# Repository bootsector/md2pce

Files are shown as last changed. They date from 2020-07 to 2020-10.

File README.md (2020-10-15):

# MD2PCE - Sega Genesis controller adapter for TG16/PC-Engine and USB!
(c) Bruno Freitas - 10/2020 - http://www.brunofreitas.com/

This project is Open Source (GPLv3) and Open Hardware (CC BY-SA 4.0)

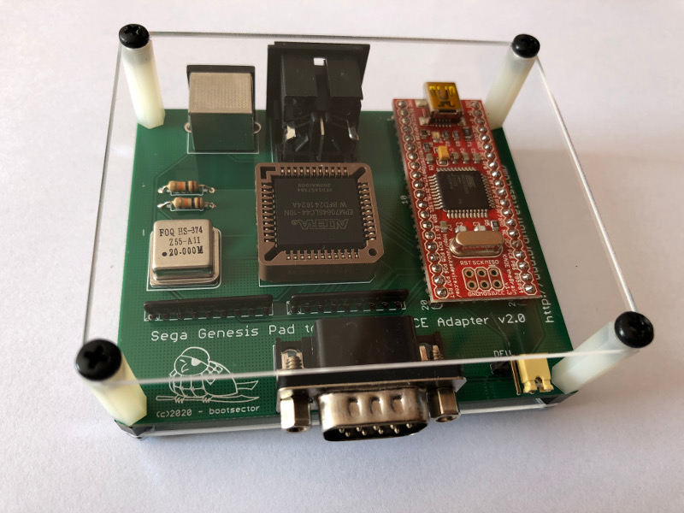
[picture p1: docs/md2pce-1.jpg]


MD2PCE is an adapter that allows you to connect Sega Genesis controllers to the TurboGrafx16, PC-Engine and also PC via USB (XInput).

It's compatible with both 3 and 6 buttons Sega Genesis controllers. It also supports the 8BitDo M30 2.4g with its wireless DB9 receiver.

MD2PCE Adapter starts in 2 button mode, which ensures 100% compatibility with all PCE/TG16 games catalog. For games supporting 6 button controllers, you can switch to 6 button mode, and also switching back to 2 button mode, by pressing the combo keys: UP + B + C + Start.

Mappings for both 2 and 6 button modes are:

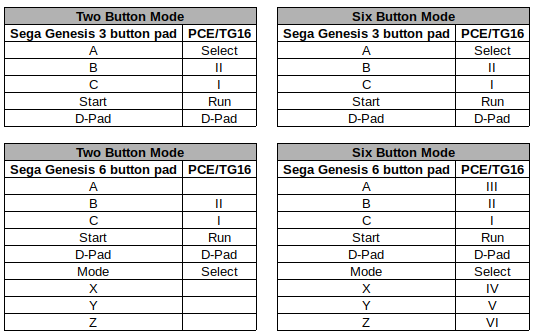
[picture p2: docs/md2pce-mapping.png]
MD2PCE Button Mapping


The adapter needs male-male 8 pin DIN (TG16) or Mini-DIN (PCE) cables that must be purchased separately.

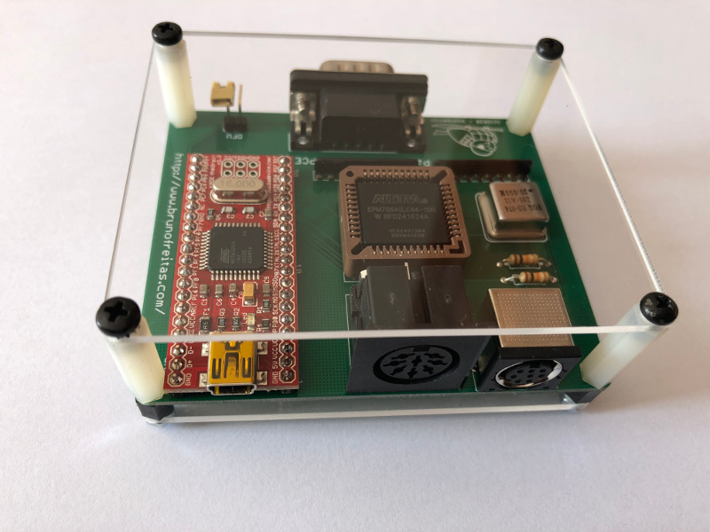
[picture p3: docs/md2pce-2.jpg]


For using on PC via USB, you'll need a mini-USB cable that also must be purchased separately.

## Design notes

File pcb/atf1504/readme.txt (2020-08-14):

This shield is based on https://github.com/hackup/ATF2FT232HQ

If CPLD is used and it needs JTAG erasing, connect a 12V PSU and run (OpenOCD version 0.10.0-rc2):

bin-x64\openocd.exe -f scripts\interface\ftdi\um232h.cfg -c "adapter_khz 400" -c "transport select jtag" -c "jtag newtap ATF1504AS tap -irlen 3 -expected-id 0x0150403f" -c init -c "svf atf1504as-erase.svf" -c "sleep 200" -c shutdown

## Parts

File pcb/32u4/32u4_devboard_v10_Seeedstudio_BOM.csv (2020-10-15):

Parts | OPL SKU | Qty
C1,C6,C7,C9 | 302010165 | 4
R1,R5 | 301010361 | 2
C8 | 302020011 | 1
XTAL | 306010037 | 1
C2,C3 | 302010143 | 2
R4 | 301010311 | 1
C4 | 302010179 | 1
R2,R3 | 301010329 | 2
32U4-AU | 310010010 | 1
F1 | 307010002 | 1
Led | 304090046 | 1
USB | 320010014 | 1

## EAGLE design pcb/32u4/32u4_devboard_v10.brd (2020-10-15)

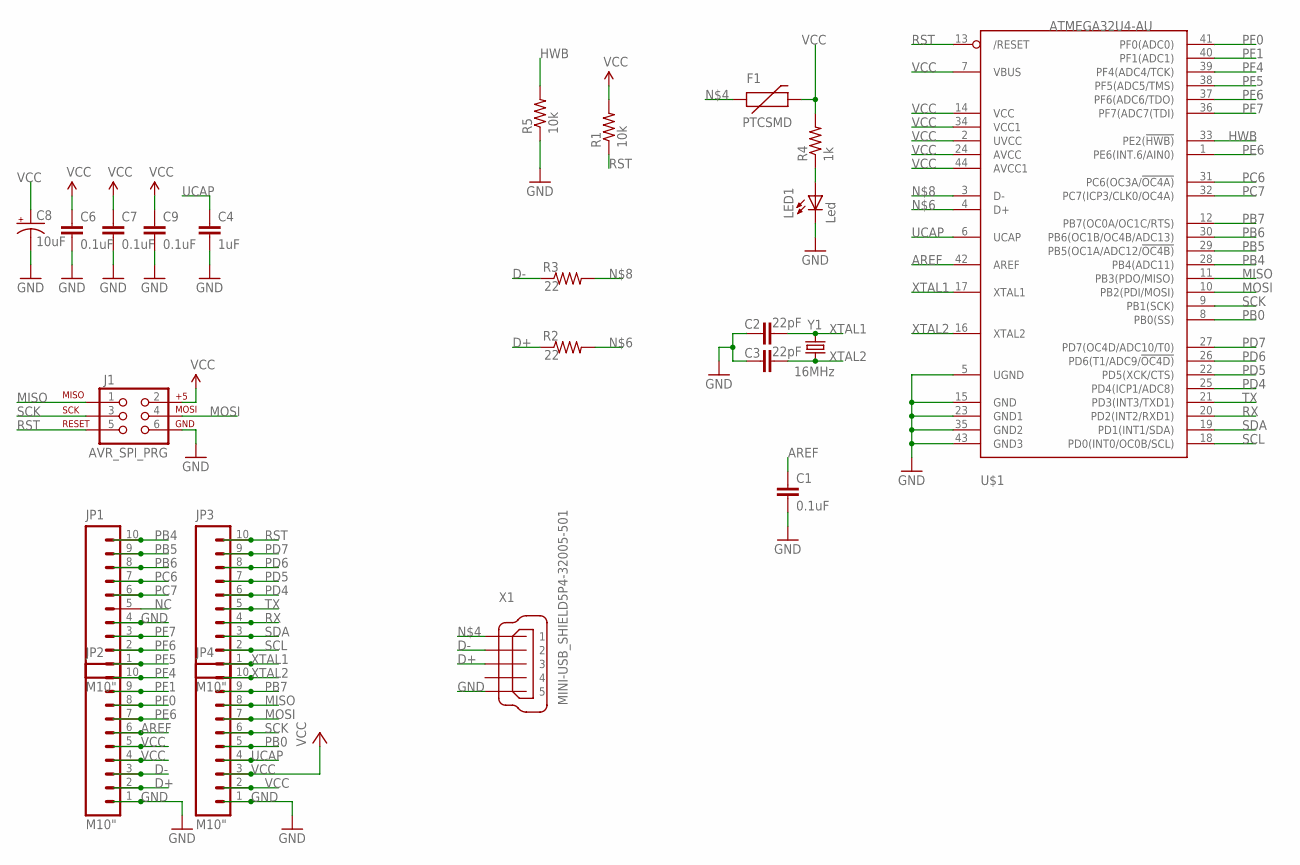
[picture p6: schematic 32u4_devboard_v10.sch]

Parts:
C1, C6, C7, C9: 0.1uF; 0805
C2, C3: 22pF; 0603-CAP
C4: 1uF; 0805
C8: 10uF; EIA3216
F1: PTCSMD; PTC-1206
J1: AVR_SPI_PRG; 2X3
JP1, JP2, JP3, JP4: M10"; 1X10
LED1: Led; CHIP-LED0805
R1, R5: 10k; 0805
R2, R3: 22; 0805
R4: 1k; 0805
U$1: ATMEGA32U4-AU; TQFP44
X1: MINI-USB_SHIELD5P4-32005-501; 32005-501
Y1: 16MHz; HC49US

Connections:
AREF: C1.1, JP2.6, U$1.42 (AREF)
D+: JP2.2, R2.1, X1.3
D-: JP2.3, R3.1, X1.2
GND: C1.2, C2.1, C3.1, C4.2, C6.2, C7.2, C8.C (-), C9.2, J1.6, JP1.4, JP2.1, JP4.1, LED1.C, R5.1, U$1.5 (UGND), U$1.15 (GND), U$1.23 (GND1), U$1.35 (GND2), U$1.43 (GND3), X1.5
HWB: R5.2, U$1.33 (PE2(!HWB))
MISO: J1.1, JP4.8, U$1.11 (PB3(PDO/MISO))
MOSI: J1.4, JP4.7, U$1.10 (PB2(PDI/MOSI))
unnamed: F1.1, X1.1
unnamed: R2.2, U$1.4 (D+)
unnamed: R3.2, U$1.3 (D-)
unnamed: LED1.A, R4.1
NC: JP1.5
PB0: JP4.5, U$1.8 (PB0(SS))
PB4: JP1.10, U$1.28 (PB4(ADC11))
PB5: JP1.9, U$1.29 (PB5(OC1A/ADC12/!OC4B))
PB6: JP1.8, U$1.30 (PB6(OC1B/OC4B/ADC13))
PB7: JP4.9, U$1.12 (PB7(OC0A/OC1C/RTS))
PC6: JP1.7, U$1.31 (PC6(OC3A/!OC4A))
PC7: JP1.6, U$1.32 (PC7(ICP3/CLK0/OC4A))
PD4: JP3.6, U$1.25 (PD4(ICP1/ADC8))
PD5: JP3.7, U$1.22 (PD5(XCK/CTS))
PD6: JP3.8, U$1.26 (PD6(T1/ADC9/!OC4D))
PD7: JP3.9, U$1.27 (PD7(OC4D/ADC10/T0))
PE6: JP2.7, U$1.1 (PE6(INT.6/AIN0))
PF0: JP2.8, U$1.41 (PF0(ADC0))
PF1: JP2.9, U$1.40 (PF1(ADC1))
PF4: JP2.10, U$1.39 (PF4(ADC4/TCK))
PF5: JP1.1, U$1.38 (PF5(ADC5/TMS))
PF6: JP1.2, U$1.37 (PF6(ADC6/TDO))
PF7: JP1.3, U$1.36 (PF7(ADC7(TDI))
RST: J1.5, JP3.10, R1.1, U$1.13 (/RESET)
RX: JP3.4, U$1.20 (PD2(INT2/RXD1))
SCK: J1.3, JP4.6, U$1.9 (PB1(SCK))
SCL: JP3.2, U$1.18 (PD0(INT0/OC0B/SCL))
SDA: JP3.3, U$1.19 (PD1(INT1/SDA))
TX: JP3.5, U$1.21 (PD3(INT3/TXD1))
UCAP: C4.1, JP4.4, U$1.6 (UCAP)
VCC: C6.1, C7.1, C8.A (+), C9.1, F1.2, J1.2, JP2.4, JP2.5, JP4.2, JP4.3, R1.2, R4.2, U$1.2 (UVCC), U$1.7 (VBUS), U$1.14 (VCC), U$1.24 (AVCC), U$1.34 (VCC1), U$1.44 (AVCC1)
XTAL1: C2.2, JP3.1, U$1.17 (XTAL1), Y1.2
XTAL2: C3.2, JP4.10, U$1.16 (XTAL2), Y1.1

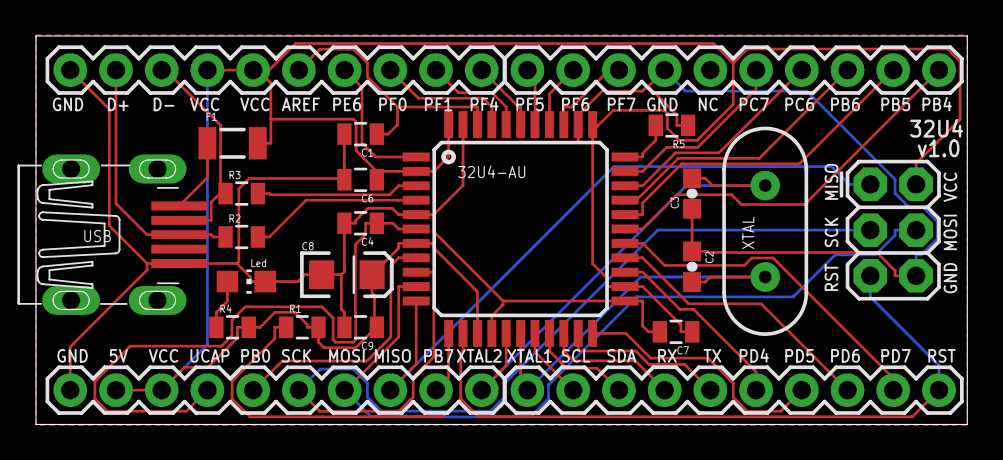
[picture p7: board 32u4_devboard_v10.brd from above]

Board: 2 copper layers, 51.7 x 21.6 mm, 23 parts (0 on the bottom side), 39 nets.

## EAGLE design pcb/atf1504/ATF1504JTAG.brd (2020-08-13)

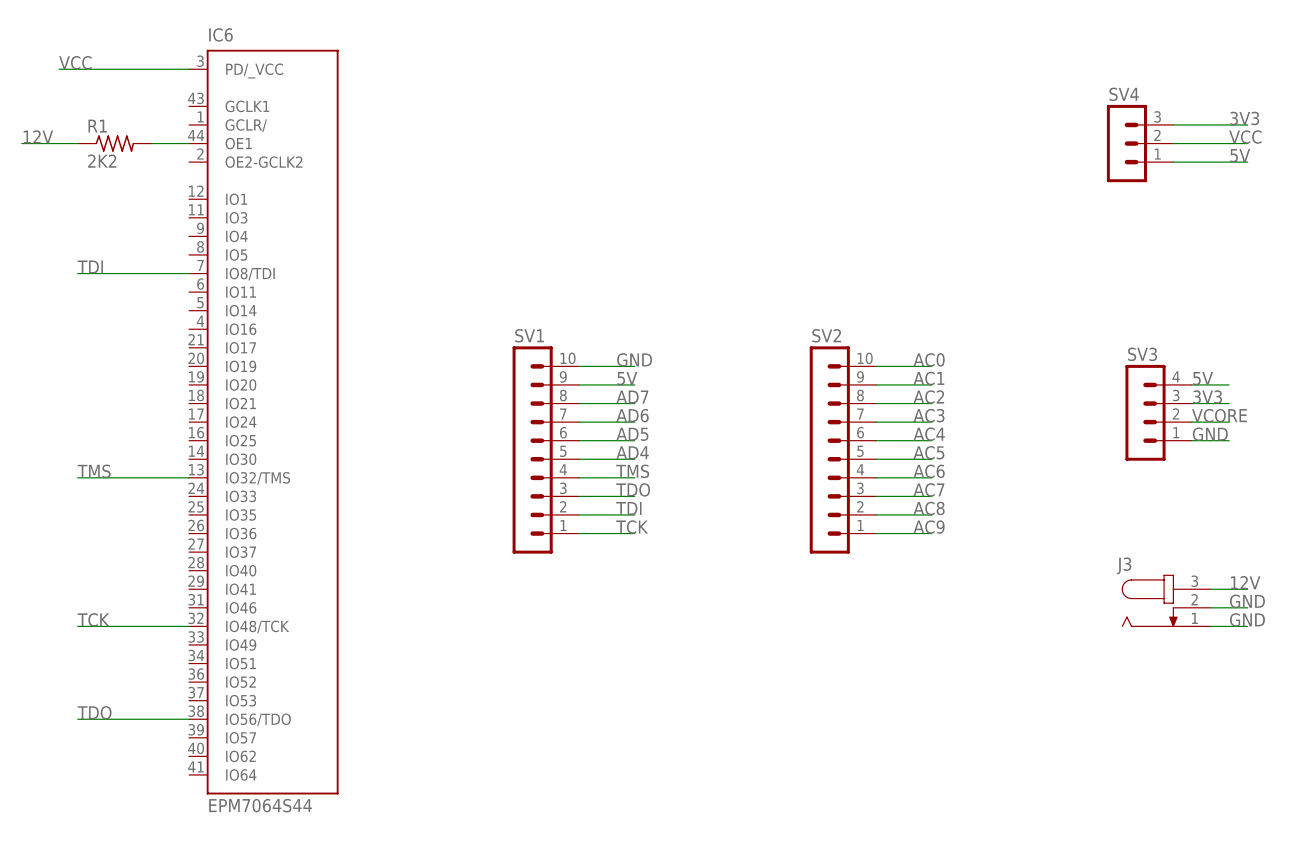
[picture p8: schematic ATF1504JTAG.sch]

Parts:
IC6: EPM7064S44; PLCC-S44
J3: JACK-PLUG1; SPC4078
R1: 2K2; 0207/10
SV1, SV2: MA10-1
SV3: MA04-1
SV4: MA03-1

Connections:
3V3: SV3.3, SV4.3
5V: SV1.9, SV3.4, SV4.1
12V: J3.3, R1.1
AC0: SV2.10
AC1: SV2.9
AC2: SV2.8
AC3: SV2.7
AC4: SV2.6
AC5: SV2.5
AC6: SV2.4
AC7: SV2.3
AC8: SV2.2
AC9: SV2.1
AD4: SV1.5
AD5: SV1.6
AD6: SV1.7
AD7: SV1.8
GND: IC6.10 (GND), IC6.22 (GND), IC6.30 (GND), IC6.42 (GND), J3.1, J3.2, SV1.10, SV3.1
unnamed: IC6.44 (OE1), R1.2
TCK: IC6.32 (IO48/TCK), SV1.1
TDI: IC6.7 (IO8/TDI), SV1.2
TDO: IC6.38 (IO56/TDO), SV1.3
TMS: IC6.13 (IO32/TMS), SV1.4
VCC: IC6.3 (PD/_VCC), IC6.15 (VCC), IC6.23 (VCC), IC6.35 (VCC), SV4.2
VCORE: SV3.2

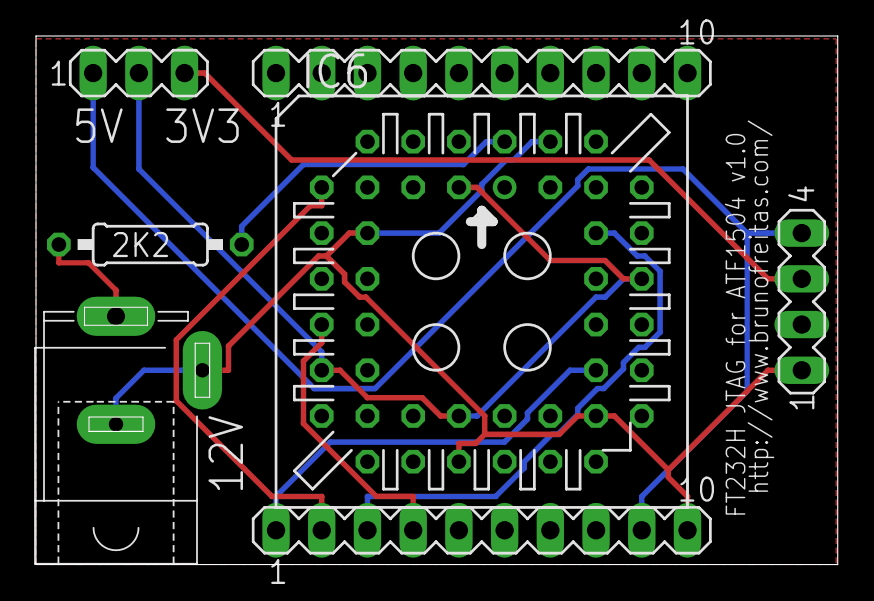
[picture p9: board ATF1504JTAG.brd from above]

Board: 2 copper layers, 44.5 x 29.4 mm, 7 parts (0 on the bottom side), 10 nets.

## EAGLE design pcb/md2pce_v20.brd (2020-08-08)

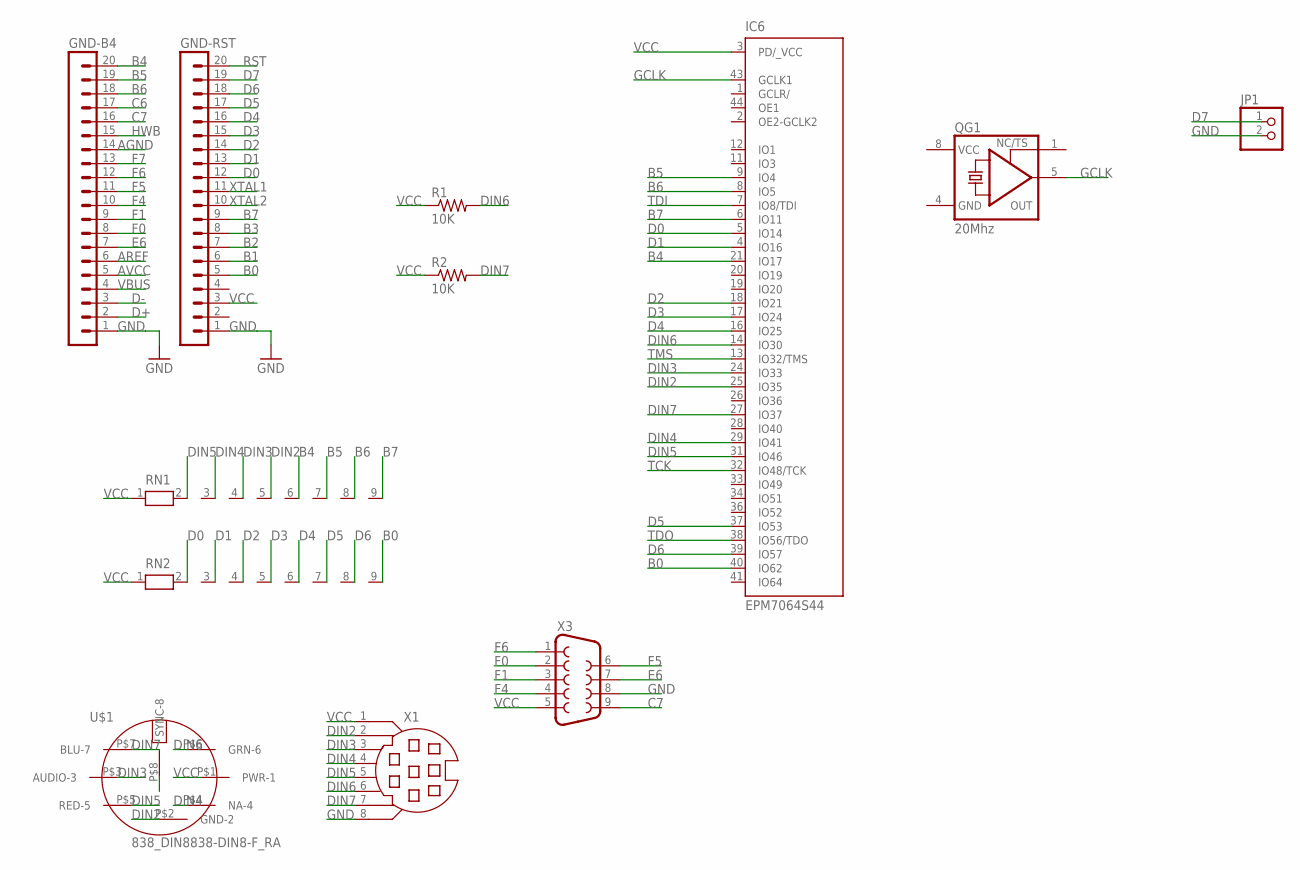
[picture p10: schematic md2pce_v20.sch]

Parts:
GND-B4: MA20-1
GND-RST: MA20-1
IC6: EPM7064S44; PLCC-S44
JP1: PINHD-1X2; 1X02
QG1: 20Mhz; DIL08S
R1, R2: 10K; 0207/10
RN1, RN2: RN08; RN-9
U$1: 838_DIN8838-DIN8-F_RA; 838_DIN8
X1: MD08SS; MDIN08SS
X3: DB9MALE; DB9_MALE

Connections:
AGND: GND-B4.14
AREF: GND-B4.6
AVCC: GND-B4.5
B0: GND-RST.5, IC6.40 (IO62), RN2.9
B1: GND-RST.6
B2: GND-RST.7
B3: GND-RST.8
B4: GND-B4.20, IC6.21 (IO17), RN1.6
B5: GND-B4.19, IC6.9 (IO4), RN1.7
B6: GND-B4.18, IC6.8 (IO5), RN1.8
B7: GND-RST.9, IC6.6 (IO11), RN1.9
C6: GND-B4.17
C7: GND-B4.16, X3.9
D0: GND-RST.12, IC6.5 (IO14), RN2.2
D1: GND-RST.13, IC6.4 (IO16), RN2.3
D2: GND-RST.14, IC6.18 (IO21), RN2.4
D3: GND-RST.15, IC6.17 (IO24), RN2.5
D4: GND-RST.16, IC6.16 (IO25), RN2.6
D5: GND-RST.17, IC6.37 (IO53), RN2.7
D6: GND-RST.18, IC6.39 (IO57), RN2.8
D7: GND-RST.19, JP1.1
D+: GND-B4.2
D-: GND-B4.3
DIN2: IC6.25 (IO35), RN1.5, U$1.P$2 (GND-2), X1.2
DIN3: IC6.24 (IO33), RN1.4, U$1.P$3 (AUDIO-3), X1.3
DIN4: IC6.29 (IO41), RN1.3, U$1.P$4 (NA-4), X1.4
DIN5: IC6.31 (IO46), RN1.2, U$1.P$5 (RED-5), X1.5
DIN6: IC6.14 (IO30), R1.2, U$1.P$6 (GRN-6), X1.6
DIN7: IC6.27 (IO37), R2.2, U$1.P$7 (BLU-7), X1.7
E6: GND-B4.7, X3.7
F0: GND-B4.8, X3.2
F1: GND-B4.9, X3.3
F4: GND-B4.10, X3.4
F5: GND-B4.11, X3.6
F6: GND-B4.12, X3.1
F7: GND-B4.13
GCLK: IC6.43 (GCLK1), QG1.5 (OUT)
GND: GND-B4.1, GND-RST.1, IC6.10 (GND), IC6.22 (GND), IC6.30 (GND), IC6.42 (GND), JP1.2, QG1.4 (GND), U$1.P$8 (SYNC-8), X1.8, X3.8
HWB: GND-B4.15
RST: GND-RST.20
TCK: IC6.32 (IO48/TCK)
TDI: IC6.7 (IO8/TDI)
TDO: IC6.38 (IO56/TDO)
TMS: IC6.13 (IO32/TMS)
VBUS: GND-B4.4
VCC: GND-RST.3, IC6.3 (PD/_VCC), IC6.15 (VCC), IC6.23 (VCC), IC6.35 (VCC), QG1.8 (VCC), R1.1, R2.1, RN1.1, RN2.1, U$1.P$1 (PWR-1), X1.1, X3.5
XTAL1: GND-RST.11
XTAL2: GND-RST.10

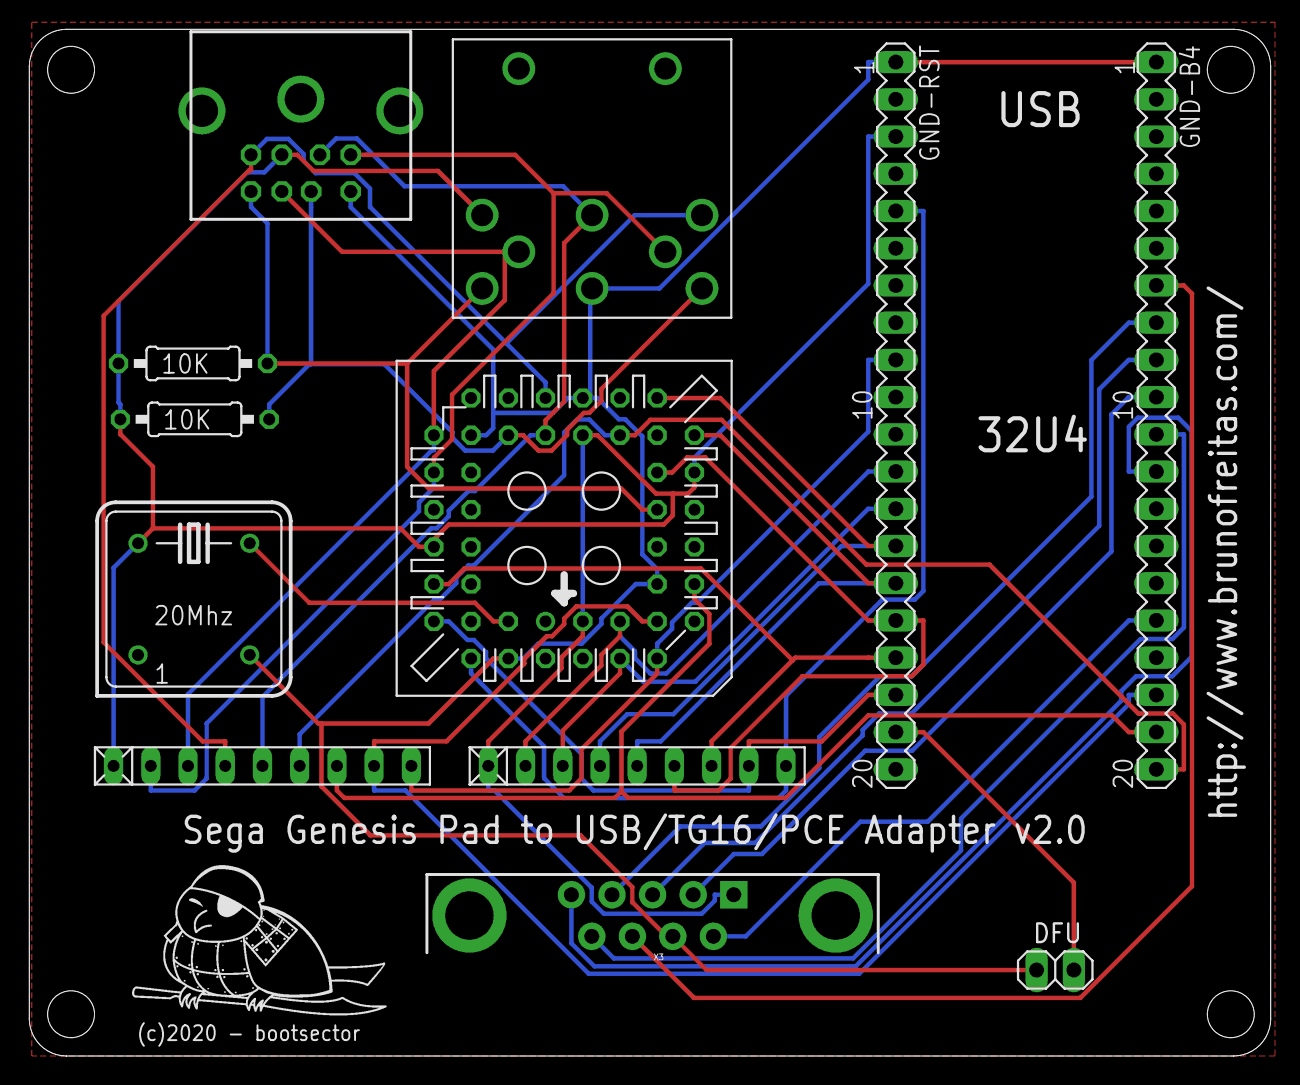
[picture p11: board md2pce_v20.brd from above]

Board: 2 copper layers, 84.7 x 70.1 mm, 12 parts (0 on the bottom side), 29 nets.

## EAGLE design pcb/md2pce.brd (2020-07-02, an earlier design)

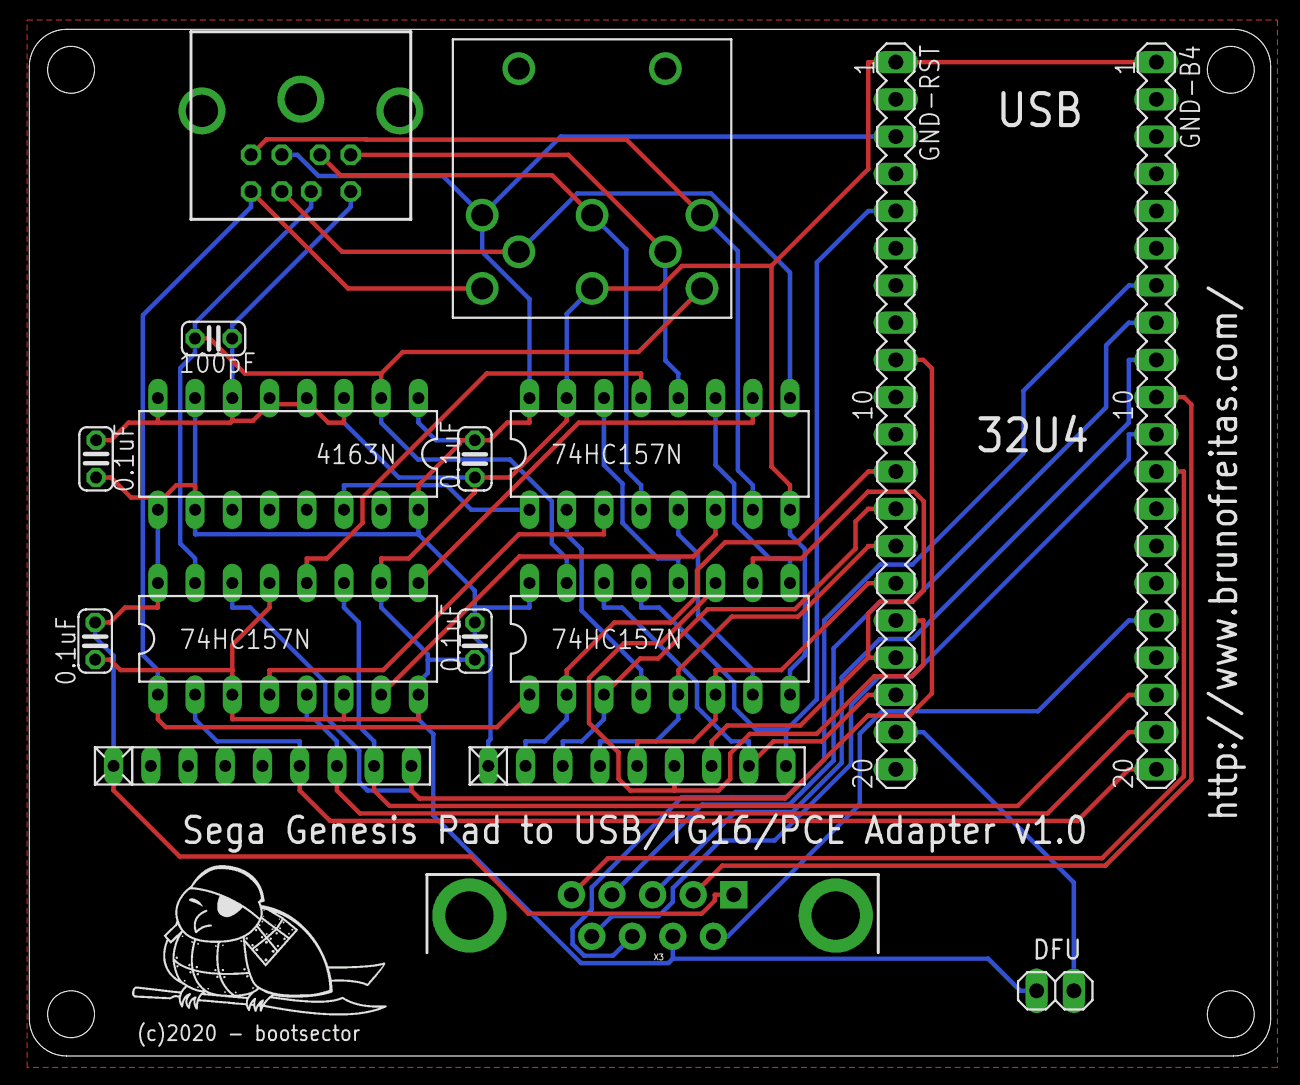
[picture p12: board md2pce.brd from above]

Board: 2 copper layers, 84.7 x 70.1 mm, 17 parts (0 on the bottom side), 37 nets.

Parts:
C1, C2, C3, C4: 0.1uF; C025-024X044
C5: 100pF; C025-024X044
GND-B4: MA20-1
GND-RST: MA20-1
IC1, IC2, IC3: 74HC157N; DIL16
IC4: 4163N; DIL16
JP1: 1X02
RN1, RN2: RN-9
U$1: 838_DIN8838-DIN8-F_RA; 838_DIN8
X1: MDIN08SS
X3: DB9_MALE

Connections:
B0: GND-RST.5, IC2.13, RN2.9
B4: GND-B4.20, IC1.2, RN1.6
B5: GND-B4.19, IC1.5, RN1.7
B6: GND-B4.18, IC1.11, RN1.8
B7: GND-RST.9, IC1.14, RN1.9
C7: GND-B4.16, X3.9
D0: GND-RST.12, IC2.2, RN2.2
D1: GND-RST.13, IC2.3, RN2.3
D2: GND-RST.14, IC2.5, RN2.4
D3: GND-RST.15, IC2.6, RN2.5
D4: GND-RST.16, IC2.11, RN2.6
D5: GND-RST.17, IC2.10, RN2.7
D6: GND-RST.18, IC2.14, RN2.8
D7: GND-RST.19, JP1.1
DIN2: IC3.4, U$1.P$2, X1.2
DIN3: IC3.7, U$1.P$3, X1.3
DIN4: IC3.9, U$1.P$4, X1.4
DIN5: IC3.12, U$1.P$5, X1.5
DIN6: IC1.1, IC2.1, U$1.P$6, X1.6
DIN7: C5.1, IC1.15, IC2.15, IC4.2, U$1.P$7, X1.7
E6: GND-B4.7, X3.7
F0: GND-B4.8, X3.2
F1: GND-B4.9, X3.3
F4: GND-B4.10, X3.4
F5: GND-B4.11, X3.6
F6: GND-B4.12, X3.1
GND: C1.2, C2.2, C3.2, C4.2, C5.2, GND-B4.1, GND-RST.1, IC1.3, IC1.6, IC1.8, IC1.10, IC1.13, IC2.8, IC3.8, IC3.15, IC4.3, IC4.4, IC4.5, IC4.6, IC4.8, JP1.2, U$1.P$8, X1.8, X3.8
unnamed: IC1.4, IC3.3
unnamed: IC1.7, IC3.6
unnamed: IC1.9, IC3.10
unnamed: IC1.12, IC3.13
unnamed: IC2.4, IC3.2
unnamed: IC2.7, IC3.5
unnamed: IC2.9, IC3.11
unnamed: IC2.12, IC3.14
unnamed: IC3.1, IC4.14
VCC: C1.1, C2.1, C3.1, C4.1, GND-RST.3, IC1.16, IC2.16, IC3.16, IC4.1, IC4.7, IC4.9, IC4.10, IC4.16, RN1.1, RN2.1, U$1.P$1, X1.1, X3.5

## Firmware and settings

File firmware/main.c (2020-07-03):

/*
* MD2PCE - Sega Genesis Pad Adapter to USB/TG16/PCE
*
* Copyright (c) 2020
* Bruno Freitas - bruno@brunofreitas.com - http://www.brunofreitas.com/
*
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
* You should have received a copy of the GNU General Public License
* along with this program. If not, see <http://www.gnu.org/licenses/>.
*/

#include <avr/io.h>

#include "Input.h"
#include "Output.h"
#include "Util.h"

AbstractPad_t PadData_DB9;

int main(void) {

	// Set clock @ 16Mhz
	CPU_PRESCALE(0);

	// Disable JTAG
	bit_set(MCUCR, 1 << JTD);
	bit_set(MCUCR, 1 << JTD);

	// Reset pad data buffers
	AbstractPad_ResetBuffer(&PadData_DB9);

	// Initialize TG16/PCE and USB interfaces
	Output_Init();

	// Initialize DB9 interface
	Input_Init();

	// Main loop
	for (;;) {
		Input_GetPadState(&PadData_DB9);

		Output_SetPadState(&PadData_DB9);
	}
}

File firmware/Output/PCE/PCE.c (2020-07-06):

/*
* MD2PCE - Sega Genesis Pad Adapter to USB/TG16/PCE
*
* Copyright (c) 2020
* Bruno Freitas - bruno@brunofreitas.com - http://www.brunofreitas.com/
*
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
* You should have received a copy of the GNU General Public License
* along with this program. If not, see <http://www.gnu.org/licenses/>.
*/

#include <avr/io.h>
#include <util/delay.h>

#include "PCE.h"
#include "Util.h"

static uint8_t _DDRD, _DDRB;

void PCE_Init(void) {
	// I
	bit_clear(DDRD, 1 << 0);
	bit_clear(PORTD, 1 << 0);

	// Up
	bit_clear(DDRD, 1 << 1);
	bit_clear(PORTD, 1 << 1);

	// II
	bit_clear(DDRD, 1 << 2);
	bit_clear(PORTD, 1 << 2);

	// Right
	bit_clear(DDRD, 1 << 3);
	bit_clear(PORTD, 1 << 3);

	// SELECT
	bit_clear(DDRD, 1 << 4);
	bit_clear(PORTD, 1 << 4);

	// DOWN
	bit_clear(DDRD, 1 << 5);
	bit_clear(PORTD, 1 << 5);

	// START
	bit_clear(DDRD, 1 << 6);
	bit_clear(PORTD, 1 << 6);

	// Left
	bit_clear(DDRB, 1 << 0);
	bit_clear(PORTB, 1 << 0);

	// III
	bit_clear(DDRB, 1 << 4);
	bit_clear(PORTB, 1 << 4);						

	// IV
	bit_clear(DDRB, 1 << 5);
	bit_clear(PORTB, 1 << 5);						

	// V
	bit_clear(DDRB, 1 << 6);
	bit_clear(PORTB, 1 << 6);						

	// VI
	bit_clear(DDRB, 1 << 7);
	bit_clear(PORTB, 1 << 7);						
}

void PCE_SetPadData(AbstractPad_t *padData)  {

	_DDRD = DDRD;
	_DDRB = DDRB;

	padData->d_up    ? bit_set(_DDRD, 1 << 1) : bit_clear(_DDRD, 1 << 1);
	padData->d_down  ? bit_set(_DDRD, 1 << 5) : bit_clear(_DDRD, 1 << 5);
	padData->d_left  ? bit_set(_DDRB, 1 << 0) : bit_clear(_DDRB, 1 << 0);
	padData->d_right ? bit_set(_DDRD, 1 << 3) : bit_clear(_DDRD, 1 << 3);

	padData->start ? bit_set(_DDRD, 1 << 6) : bit_clear(_DDRD, 1 << 6);
	padData->back  ? bit_set(_DDRD, 1 << 4) : bit_clear(_DDRD, 1 << 4);

	padData->a ? bit_set(_DDRD, 1 << 2) : bit_clear(_DDRD, 1 << 2);
	padData->b ? bit_set(_DDRD, 1 << 0) : bit_clear(_DDRD, 1 << 0);
	padData->x ? bit_set(_DDRB, 1 << 4) : bit_clear(_DDRB, 1 << 4);
	padData->y ? bit_set(_DDRB, 1 << 6) : bit_clear(_DDRB, 1 << 6);

	padData->lb ? bit_set(_DDRB, 1 << 5) : bit_clear(_DDRB, 1 << 5);
	padData->rb ? bit_set(_DDRB, 1 << 7) : bit_clear(_DDRB, 1 << 7);

	DDRD = _DDRD;
	DDRB = _DDRB;
}

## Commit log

2020-07-03 Adding acrylic case designs
2020-07-06 Fixing temp variables type
    [PCE.c]
2020-08-07 Start working on verilog module for a PCE 6 button encoder
2020-08-07 PCE verilog encoder WIP
2020-08-08 PCB version 2.0 (using CPLD). Added Quartus project files.
    [md2pce.sch, md2pce_v20.brd, md2pce_v20.sch]
2020-08-13 Added gerber for an Atmel ATF1504 JTAG programmer shield for cheap FT232 module
    [ATF1504JTAG.brd, ATF1504JTAG.sch]
2020-09-09 Adding 1ms timer
2020-09-09 Improves 1ms timer against jitter
2020-09-09 Removed overall debounce logic and improved Genesis 6 button required delay logic
2020-09-09 500us delay looks enough for a 6 button controller settling between reads.
2020-10-04 Improved reading of sega genesis 6 button controller - removed 500us busy delay
2020-10-04 Revert "Improved reading of sega genesis 6 button controller - removed 500us busy delay"
    This reverts commit 2b43a497c3b5f5f0b78716028848ced92a060647.
    [Genesis_In.c]
2020-10-08 Corrected inverted bits in Verilog PCE encoder. Hyperkin six button controller needs bigger delay between reads.
    [Genesis_In.c]
2020-10-09 Added combo for switching between 2 and 6 button mode output (thanks @brNX). Mapping A to SELECT for 3 button sega genesis controllers
2020-10-13 Improved compatibility with six button hyperkin controllers
2020-10-15 Added Atmega 32u4 board schematics and gerber files
    [32u4_devboard_v10.brd, 32u4_devboard_v10.sch, 32u4_devboard_v10_Seeedstudio_BOM.csv]
2022-09-20 Enabled Reduce MC Power for ATF1504 in SVF

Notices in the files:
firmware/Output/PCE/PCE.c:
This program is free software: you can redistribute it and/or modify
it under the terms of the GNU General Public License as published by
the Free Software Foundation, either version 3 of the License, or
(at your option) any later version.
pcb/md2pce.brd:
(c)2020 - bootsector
